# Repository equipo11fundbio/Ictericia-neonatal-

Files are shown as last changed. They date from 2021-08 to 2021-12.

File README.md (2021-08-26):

## Welcome to GitHub Pages

You can use the [editor on GitHub](https://github.com/equipo11fundbio/equipo11fundbio.github.io/edit/main/README.md) to maintain and preview the content for your website in Markdown files.

Whenever you commit to this repository, GitHub Pages will run [Jekyll](https://jekyllrb.com/) to rebuild the pages in your site, from the content in your Markdown files.

### Markdown

Markdown is a lightweight and easy-to-use syntax for styling your writing. It includes conventions for

```markdown
Syntax highlighted code block

# Header 1
## Header 2
### Header 3

- Bulleted
- List

1. Numbered
2. List

**Bold** and _Italic_ and `Code` text

[Link](url) and ![Image](src)
```

For more details see [GitHub Flavored Markdown](https://guides.github.com/features/mastering-markdown/).

### Jekyll Themes

Your Pages site will use the layout and styles from the Jekyll theme you have selected in your [repository settings](https://github.com/equipo11fundbio/equipo11fundbio.github.io/settings/pages). The name of this theme is saved in the Jekyll `_config.yml` configuration file.

### Support or Contact

Having trouble with Pages? Check out our [documentation](https://docs.github.com/categories/github-pages-basics/) or [contact support](https://support.github.com/contact) and we’ll help you sort it out.

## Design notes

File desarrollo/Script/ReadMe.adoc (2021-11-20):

:Author: coachamericano
:Email: {AuthorEmail}
:Date: 17/11/2021
:Revision: version#
:License: Public Domain

= Project: {Project}

Describe your project

== Step 1: Installation
Please describe the steps to install this project.

For example:

1. Open this file
2. Edit as you like
3. Release to the World!

== Step 2: Assemble the circuit

Assemble the circuit following the diagram layout.png attached to the sketch

== Step 3: Load the code

Upload the code contained in this sketch on to your board

=== Folder structure

....
 sketch123                => Arduino sketch folder
  ├── sketch123.ino       => main Arduino file
  ├── schematics.png      => (optional) an image of the required schematics
  ├── layout.png          => (optional) an image of the layout
  └── ReadMe.adoc         => this file
....

=== License
This project is released under a {License} License.

=== Contributing
To contribute to this project please contact coachamericano https://id.arduino.cc/coachamericano

=== BOM
Add the bill of the materials you need for this project.

|===
| ID | Part name      | Part number | Quantity
| R1 | 10k Resistor   | 1234-abcd   | 10
| L1 | Red LED        | 2345-asdf   | 5
| A1 | Arduino Zero   | ABX00066    | 1
|===

=== Help
This document is written in the _AsciiDoc_ format, a markup language to describe documents.
If you need help you can search the http://www.methods.co.nz/asciidoc[AsciiDoc homepage]
or consult the http://powerman.name/doc/asciidoc[AsciiDoc cheatsheet]

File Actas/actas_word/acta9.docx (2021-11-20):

ACTA DE REUNION N°: | 09 | Equipo N°: | 11
GRUPO HORARIO: | G3 | FECHA: | 30 /10/2021

Contenidos

Estudiantes:

- Flores Pomachagua, Alvaro Leonardo

- Vilca Mamani, Varinia Lashmy

- Rubio Gonzales, Andre Gian Pierre

- Espinoza Rossi, Angelo Paolo

- Huanca Mendoza, Alejandro Rodrigo

Temas a tratar:

- Revisar las recomendaciones del hito 2
- Corregir el diagrama modular
- Actualizar el plan de trabajo
- Modificar el presupuesto de módulo y la lista de componentes

Acuerdos:

- En el plan de trabajo cambiar los objetivos por cosas tangibles.
- Eliminar el sistema de cable retráctil en el diagrama modular.
- Cambiar la batería recargable por una de litio.
- Eliminar el diagrama de caso de uso.
- Incluir los “extras” en los componentes del módulo principal.
- Usar los componentes más baratos y dar un valor exacto.
- Usar el display OLED y el emisor de luz LED en un solo submódulo de visualización.
- Añadir una descripción del principio de funcionamiento del sensor.

Asesor:
Conformidad:

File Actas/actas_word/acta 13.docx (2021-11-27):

ACTA DE REUNION N°: | 13 | Equipo N°: | 11
GRUPO HORARIO: | G3 | FECHA: | 27/11/2021

Contenidos

Estudiantes:

- Flores Pomachagua, Alvaro Leonardo

- Vilca Mamani, Varinia Lashmy

- Rubio Gonzales, Andre Gian Pierre

- Espinoza Rossi, Angelo Paolo

- Huanca Mendoza, Alejandro Rodrigo

Temas a tratar:

- Integración del software del dispositivo
- Evaluar el funcionamiento del dispositivo para obtener la concentración de bilirrubina.
- Arreglo de la estructura del hardware del dispositivo.
- Revisar los requerimientos del diseño .
- Revisión de la página web y el repositorio.
- Revisión del Informe.

Acuerdos:

- Realizar un video del funcionamiento del dispositivo integrado.
- Realizar una prueba con ejemplos de color.
- Corrección del código , al menos mostrando los valores recolectados en el monitor principal.
- Acortar cables y limar el modelado para el correcto encaje del hardware.
- Corregir los requerimientos del diseño .
- Ordenar la información del desarrollo de la página web.
- Resumir y colocar menos antecedentes, explayar el resumen, colocar imágenes del dispositivo, ordenar las partes del informe.

Asesor:
Conformidad:

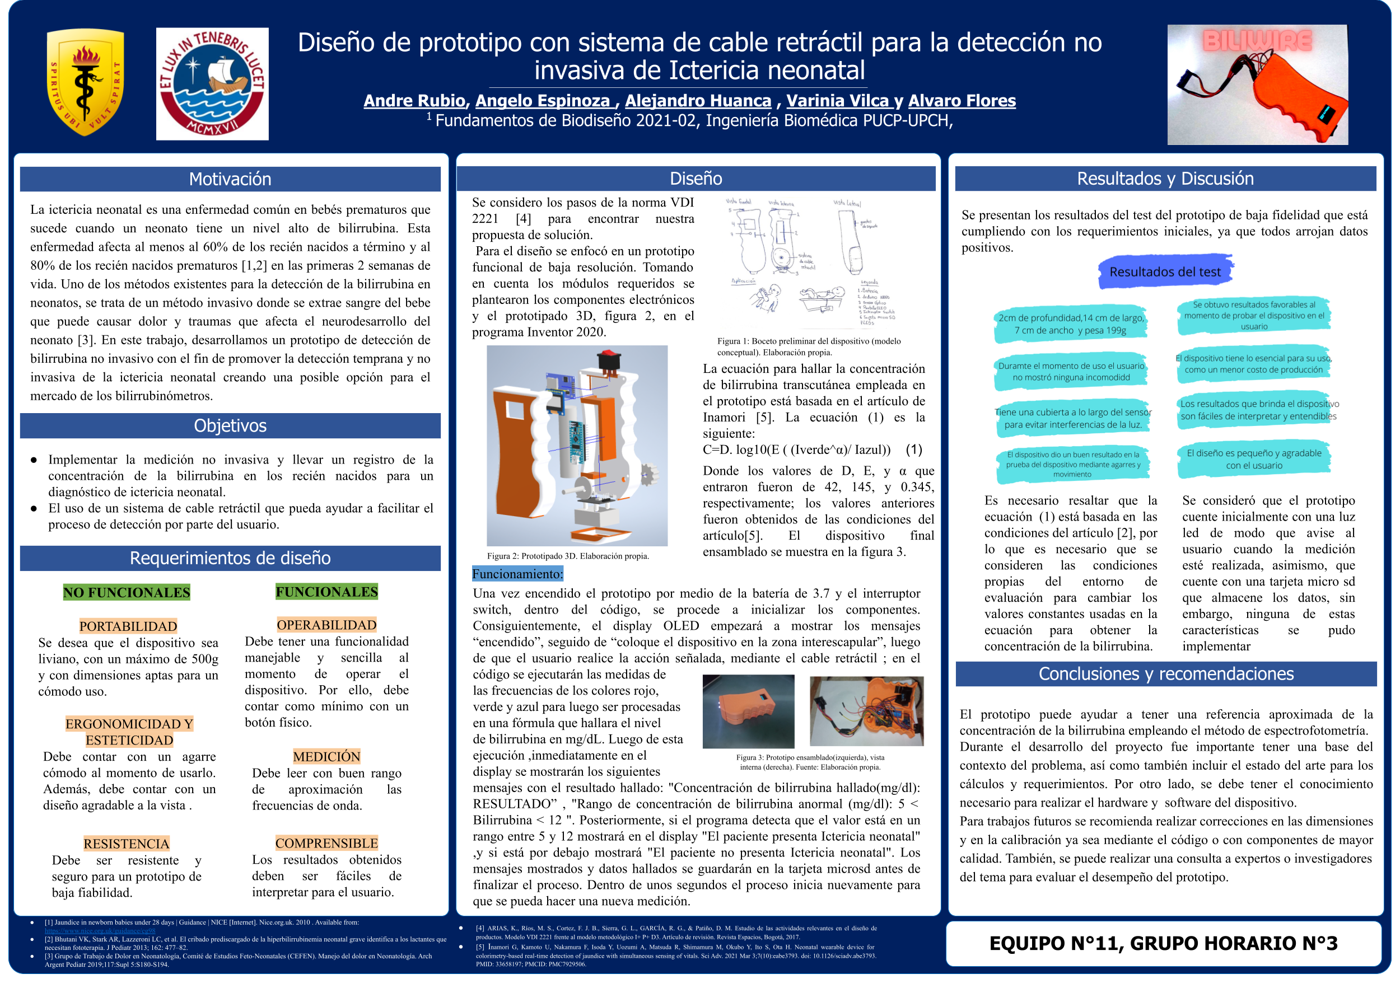
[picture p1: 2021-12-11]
Poster -FundBio2021-2_TamañoA1.pptx (2).png

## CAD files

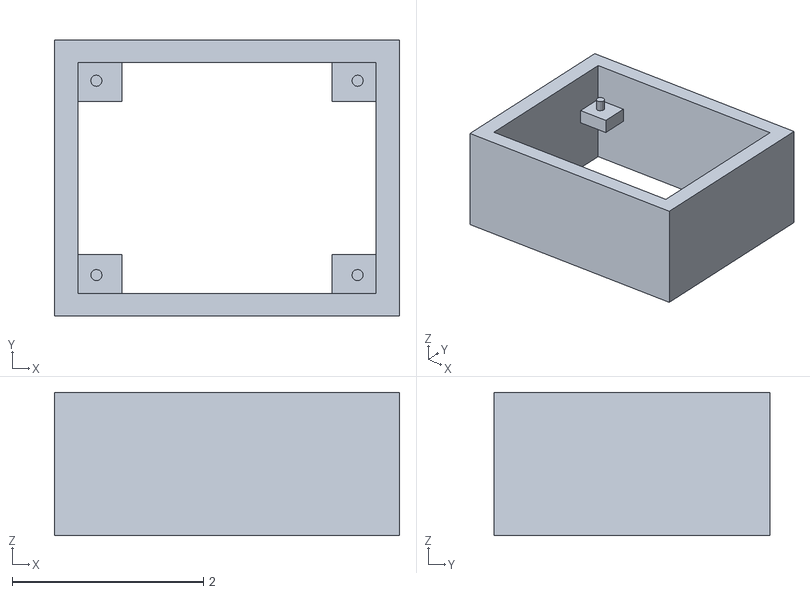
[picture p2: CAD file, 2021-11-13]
desarrollo/3D-Print/3D_Print/ensamblaje del sensor externo.stl
3.61 x 2.89 x 1.50

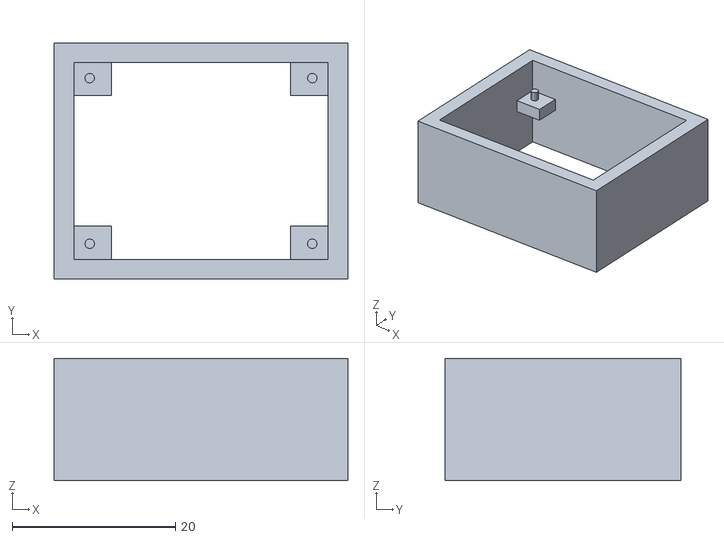
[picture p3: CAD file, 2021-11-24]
desarrollo/3D-Print/3D_print-actualizadoV3/CE3PRO_soporte sensor.stl
36.1 x 28.9 x 15.0

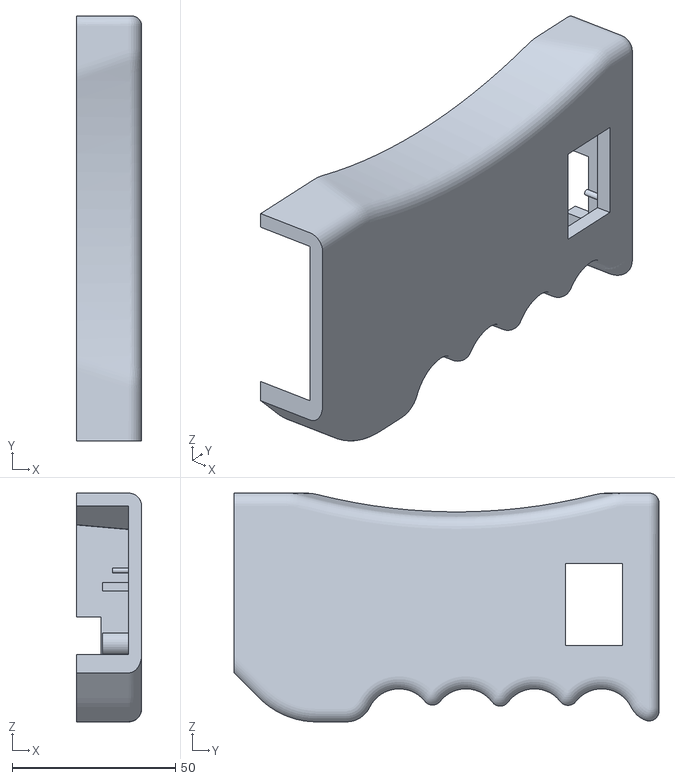
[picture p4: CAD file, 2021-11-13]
desarrollo/3D-Print/3D_Print/carcasa parte frente.stl
20.0 x 130.0 x 70.0

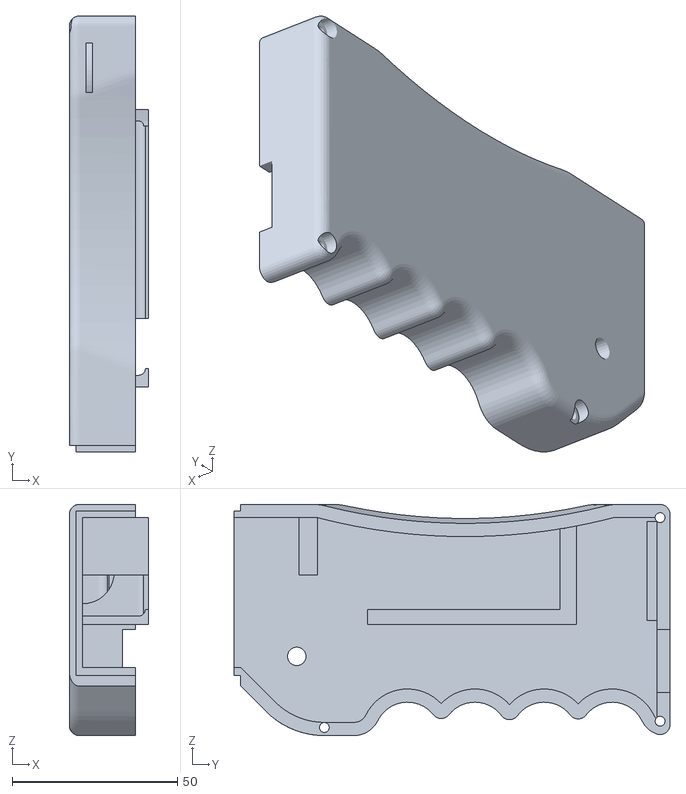
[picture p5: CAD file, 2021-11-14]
desarrollo/3D-Print/3D_print-actualizadoV3/carcasa_atras.stl
24.0 x 132.0 x 70.0

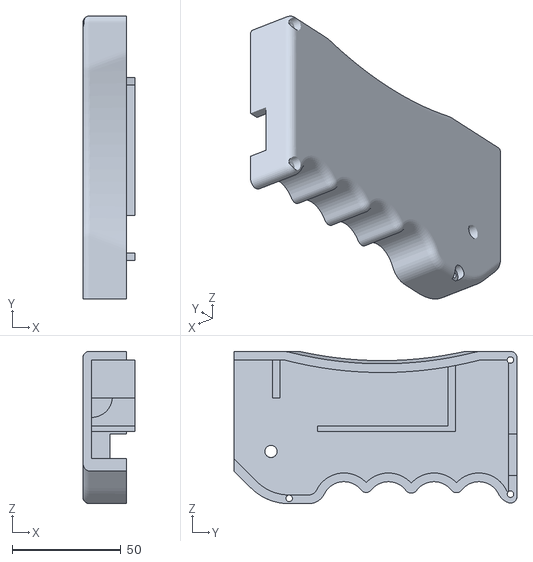
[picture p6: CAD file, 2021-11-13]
desarrollo/3D-Print/3D_Print/carcasa_atras.stl
24.0 x 130.0 x 70.0

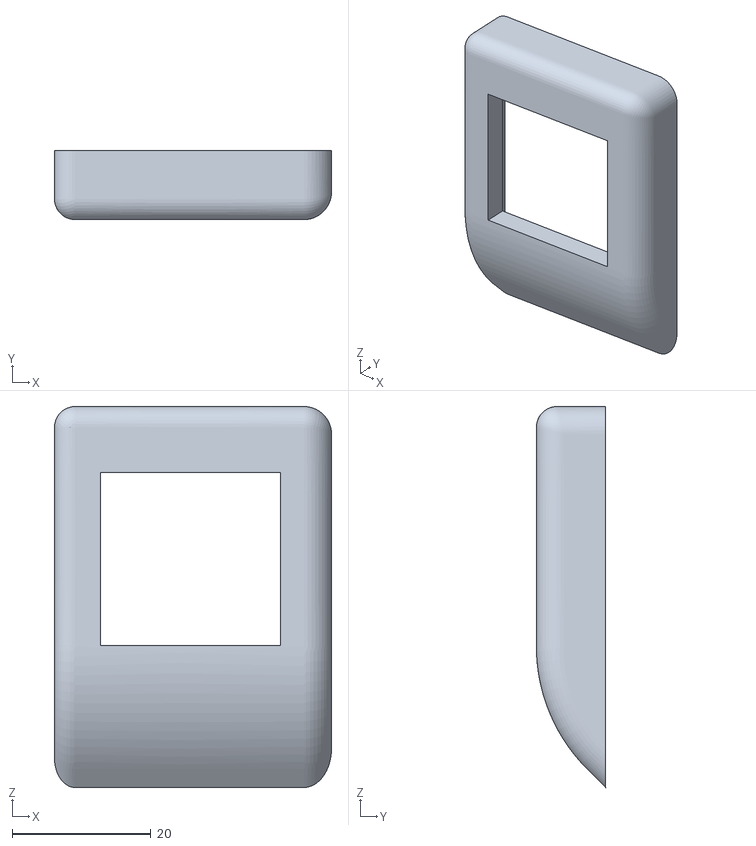
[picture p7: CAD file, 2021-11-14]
desarrollo/3D-Print/3D_print-actualizadoV3/tapa2.0_carcasa.stl
40.0 x 10.0 x 55.0

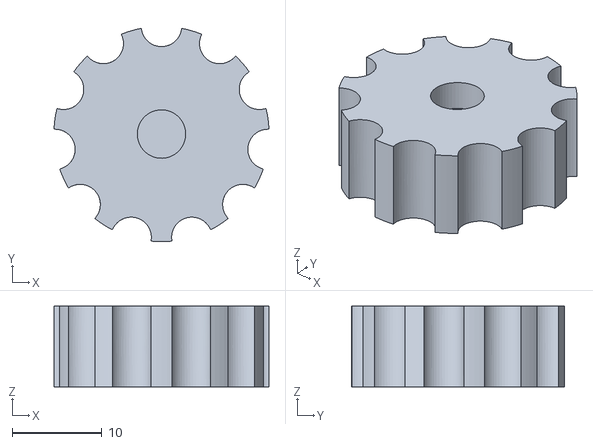
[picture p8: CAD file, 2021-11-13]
desarrollo/3D-Print/3D_Print/perilla del carrete.stl
24.0 x 23.8 x 9.00

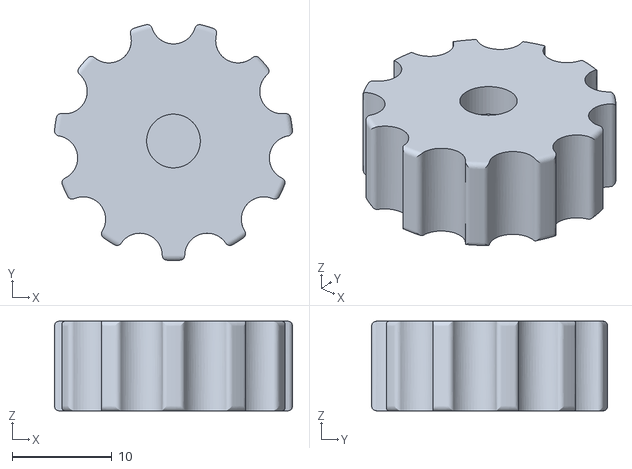
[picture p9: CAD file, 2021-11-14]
desarrollo/3D-Print/3D_print-actualizadoV3/perilla_carrete.stl
23.9 x 23.7 x 9.00

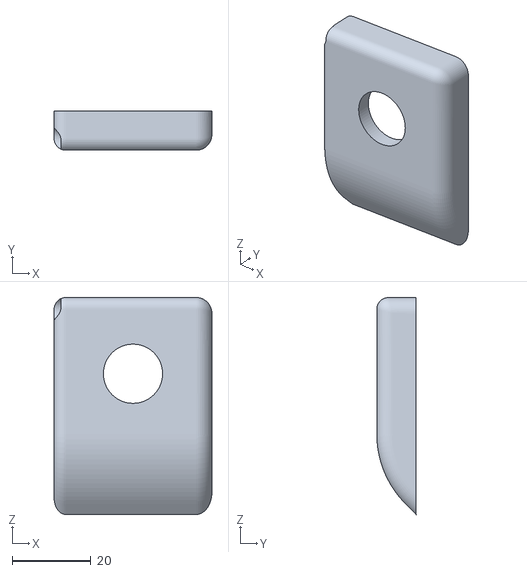
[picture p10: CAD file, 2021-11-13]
desarrollo/3D-Print/3D_Print/tapa_carcasa.stl
40.0 x 10.0 x 55.0

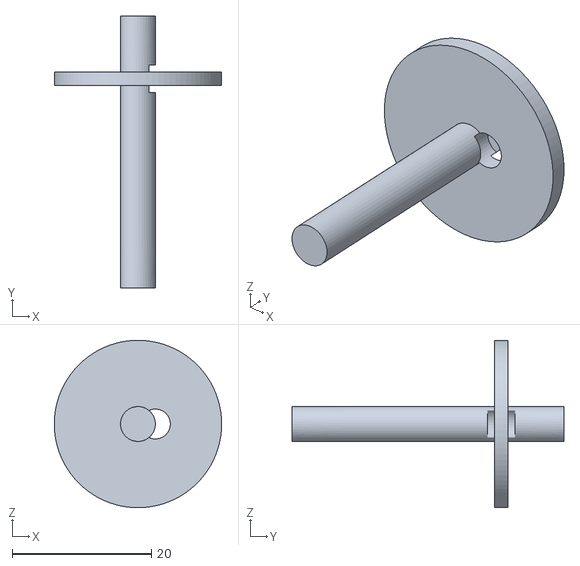
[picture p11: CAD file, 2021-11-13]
desarrollo/3D-Print/3D_print-actualizadoV3/carrete_interno.stl
24.0 x 39.0 x 24.0

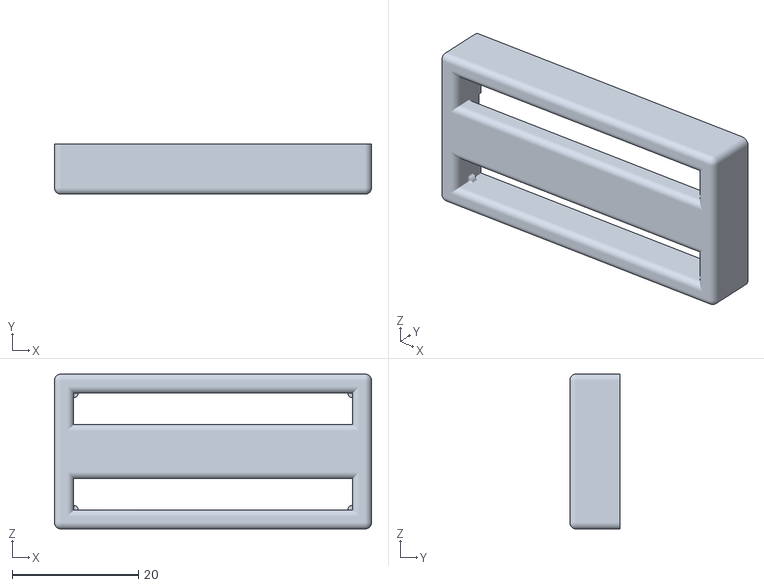
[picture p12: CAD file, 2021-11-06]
desarrollo/3D-Print/3D_Print/nano lower case.STL
50.2 x 8.00 x 24.5

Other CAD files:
desarrollo/3D-Print/3D_print-actualizadoV3/carcasa_parte_frente.stl

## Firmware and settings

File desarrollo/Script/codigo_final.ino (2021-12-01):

#include <SPI.h>
#include <Wire.h>
#include <SD.h>    
#include <Adafruit_GFX.h>
#include <Adafruit_SSD1306.h>
#define SSpin 8    
#define S0 9
#define S1 7
#define S2 2
#define S3 3
#define sensorSalida 5
int Rojo_Frec = 0;
int Verde_Frec = 0;
int Azul_Frec = 0;
int VALORSENSOR = 0;
File archivo;     // objeto archivo del tipo File
Adafruit_SSD1306 display = Adafruit_SSD1306(128, 32, &Wire);
void setup() {
  display.begin(SSD1306_SWITCHCAPVCC, 0x3C); 
  display.clearDisplay();
  display.setTextColor(SSD1306_WHITE);
  pinMode(S0, OUTPUT);
  pinMode(S1, OUTPUT);
  pinMode(S2, OUTPUT);
  pinMode(S3, OUTPUT);
  pinMode(sensorSalida, INPUT);
  
                           // Configura la escala de Frecuencia en 20%
  digitalWrite(S0,HIGH);
  digitalWrite(S1,LOW);
  
  Serial.begin(9600);
  Serial.println("Inicializando tarjeta ...");  // texto en ventana de monitor
    if (!SD.begin(SSpin)) {     // inicializacion de tarjeta SD
    Serial.println("fallo en inicializacion !");// si falla se muestra texto correspondiente y
    return;         // se sale del setup() para finalizar el programa
  }
  Serial.println("inicializacion correcta");  // texto de inicializacion correcta
  archivo = SD.open("datos.txt", FILE_WRITE); // apertura para lectura/escritura de archivo datos.txt

}
void loop(){
  if (archivo) {  
    display.clearDisplay();
    display.setTextSize(1);
    display.setCursor(0,0);
    display.print("Encendido");
    display.display(); 
    delay(3000);

    display.clearDisplay();
    display.setTextSize(1);
    display.setCursor(0,0);
    display.print("Coloque el dispositivo en la zona interescapular");
    display.display(); 
    delay(4000);

                             // Configura el filtor ROJO para tomar lectura
    digitalWrite(S2,LOW);
    digitalWrite(S3,LOW);
    delay(100);
    Rojo_Frec= pulseIn(sensorSalida, LOW);
    archivo.print("Frecuencia_rojo");
    archivo.print(":");
    archivo.println(Rojo_Frec);
    Serial.print(" R= "); Serial.print(Rojo_Frec);
    delay(100);
                            // Configura el filtor VERDE para tomar lectura
    digitalWrite(S2,HIGH);
    digitalWrite(S3,HIGH);
    delay(100);
    Verde_Frec = pulseIn(sensorSalida, LOW);
    archivo.print("Frecuencia_verde");
    archivo.print(":");
    archivo.println(Verde_Frec);
    Serial.print(" V= "); Serial.print(Verde_Frec);
    delay(100);
                           // Configura el filtor AZUL para tomar lectura
    digitalWrite(S2,LOW);
    digitalWrite(S3,HIGH);
    delay(100);
    Azul_Frec = pulseIn(sensorSalida, LOW);
    archivo.print("Frecuencia_azul");
    archivo.print(":");
    archivo.println(Azul_Frec);
    Serial.print(" A= "); Serial.print(Azul_Frec);
    delay(100);
    Serial.println("*");
    delay(200); 

    VALORSENSOR = 42*(log(145*(pow(Verde_Frec,0.345)/Azul_Frec)));
    
    
    display.clearDisplay();
    display.setTextSize(1);
    display.setCursor(0,0);
    display.print("Concentración de bilirrubina hallado(mg/dl): "); display.println(VALORSENSOR);
    display.print("Rango de concentración de bilirrubina normal (mg/dl): Bilirrubina < 5 ");
    display.display(); 
    delay(10000);
    
    archivo.print("Concentración de bilirrubina hallado");
    archivo.print(":");
    archivo.println(VALORSENSOR);
    Serial.print("Concentración de bilirrubina hallado:"); Serial.print(VALORSENSOR); Serial.println("mg/dL");
    
    if(VALORSENSOR>5){
      display.clearDisplay();
      display.setTextSize(1);
      display.setCursor(0,0);
      display.print("El paciente presenta Ictericia neonatal");
      display.display(); 
      delay(5000);
      archivo.println("El paciente presenta Ictericia neonatal");
      Serial.println("El paciente presenta Ictericia neonatal");
    } else{
    
      display.clearDisplay();
      display.setTextSize(1);
      display.setCursor(0,0);
      display.print("El paciente no presenta Ictericia neonatal");
      display.display(); 
      delay(5000);
      archivo.println("El paciente no presenta Ictericia neonatal");
      Serial.println("El paciente no presenta Ictericia neonatal");
    }
    archivo.close();        // cierre de archivo
    Serial.println("escritura correcta"); // texto de escritura correcta en monitor serie
    
  } else {
    Serial.println("error en apertura de datos.txt"); // texto de falla en apertura de archivo
    
  }
  
  }

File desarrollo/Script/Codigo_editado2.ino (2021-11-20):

#include <Wire.h>
#include <Adafruit_GFX.h>
#include <Adafruit_SSD1306.h>

#include <SPI.h>
#include <SD.h>


#define COL 128 
#define rom 64  
#define SSpin 10 

 Adafruit_SSD1306 display(COL, rom,&Wire);

 
int VALORSENSOR;

const int s0 = 1;
const int s1 = 6;
const int s2 = 2;
const int s3 = 3;
const int out = 5;



void setup() {
  
    Serial.begin (9600);
    display.begin(SSD1306_SWITCHCAPVCC, 0x3C);
    pinMode(s0, OUTPUT); 
    pinMode(s1, OUTPUT);
    pinMode(s2, OUTPUT);
    pinMode(s3, OUTPUT);
    pinMode(out, INPUT);
    
    digitalWrite(s0, HIGH);
   digitalWrite(s1, HIGH);
  
    Wire.begin();
    
    display.clearDisplay();
    display.setTextColor(SSD1306_WHITE);
    





    display.clearDisplay();
    display.setTextSize(1);
    display.setCursor(0, 0); 
    display.print("Encendido"); 
    
    display.setCursor(0, 14);
    display.print("Colocar el dispositivo en la frente para empezar");
    display.display();
    
    
    if(digitalRead(s3) == HIGH ){
      display.setCursor(0, 16);
      delay(100);
      display.print("...");
    }
    
      int AZUL = getAzul();
    delay(200);
    int VERDE = getVerde();
    delay(200);

    VALORSENSOR = 42*(log(145*(pow(VERDE,0.345)/AZUL)));
    
    display.clearDisplay();
    display.setCursor(0, 0);
    display.print("Concentración de bilirrubina hallado(mg/dl): ");
    display.println(VALORSENSOR);
    display.setCursor(0, 16);
    display.print("Rango de concentración de bilirrubina normal (mg/dl): Bilirrubina < 5 ");
    
    
  
    display.setCursor(0, 30);
    
    if(VALORSENSOR>5){
      
      display.print("El paciente presenta Ictericia neonatal");
    } else
    {
    
      display.print("El paciente no presenta Ictericia neonatal");
    }
    display.display();

    String datastring = "" ;
    datastring =String(VALORSENSOR);
    File datafile= SD.open("datalog.txt",FILE_WRITE);

}

void loop() {
}

int getAzul(){
  digitalWrite(s2, LOW);
  digitalWrite(s3, HIGH);
  int AZUL = pulseIn(out, LOW);
  return AZUL;
}

int getVerde(){
  digitalWrite(s2, HIGH);
  digitalWrite(s3, HIGH);
  int VERDE = pulseIn(out, LOW);
  return VERDE;
}

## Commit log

2021-11-06 piezas para imprimir
    1
    [CNC_Shield_Cover_Bottom.STL, CNC_Shield_Cover_Top.STL, Part10 carrete.stl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]
2021-11-06 parametros y gramos
    115 g de los archivos gcode
2021-11-10 2
    2
    [CNC_Shield_Cover_Bottom.STL, CNC_Shield_Cover_Top.STL, Part10 carrete.stl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]
2021-11-13 Modelo2
    editado modelo 2
    [carcasa parte frente.stl, carcasa_atras.stl, carrete_interno.stl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]
2021-11-13 actualizacion de archivos
    3d modelos borrados
2021-11-13 actualización de archivos stl
    eliminacion de archivos 3D del modelo1
    [CNC_Shield_Cover_Bottom.STL, CNC_Shield_Cover_Top.STL, Part10 carrete.stl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]
2021-11-14 Version 3
    -Se cambio el agarre de algunos componentes con la carcasa.
    -Se editó la forma de sujetar la parte del sensor.
    [carcasa_atras.stl, carcasa_parte_frente.stl, carrete_interno.stl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]
2021-11-14 cambio de ubicación
    Archivos actualizados en carpeta "desarrollo/Print_3D"
2021-11-14 cambio de ubicacion
    Archivos 3D en la nueva ubicación "desarrollo_3D/Print_3D", en la versión 3 (Print_3D-aclizadoV3) actualmente 13/11/21.
    [CNC_Shield_Cover_Bottom.STL, CNC_Shield_Cover_Top.STL, Part10 carrete.stl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]
2021-11-20 version final
    Diseño esquemático de circuito electrónico (versión final)
    [ROOT.DSN]
2021-11-20 2
    cambio de nombre
2021-11-20 actualización/cambio de ubicación
    cambio de ubicación
2021-11-20 actualizacion/actas_modificadas
    corrección del número de las actas
2021-11-24 pieza_soporte_sensor
    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
    [CE3PRO_soporte sensor.stl]
